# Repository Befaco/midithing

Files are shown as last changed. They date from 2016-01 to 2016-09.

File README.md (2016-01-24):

# MIDI Thing
Firmware for the [Befaco](http://befaco.org) Eurorack MIDI module (MIDI Thing).

## Requirements
You need Arduino >= 1.6.3.

Additionally you will need the following libraries installed (see the [Arduino Guide](https://www.arduino.cc/en/Guide/Libraries) on how to do this):

* [MIDI](https://github.com/FortySevenEffects/arduino_midi_library)
* [Bounce](https://github.com/thomasfredericks/Bounce2) (currently Bounce1 is needed. Please use it [until we've moved to Bounce2](https://github.com/Befaco/midithing/issues/3)).
* [mcp4728](https://code.google.com/p/neuroelec/downloads/detail?name=mcp4728_library-v1.3.zip)

## Uploading the firmware

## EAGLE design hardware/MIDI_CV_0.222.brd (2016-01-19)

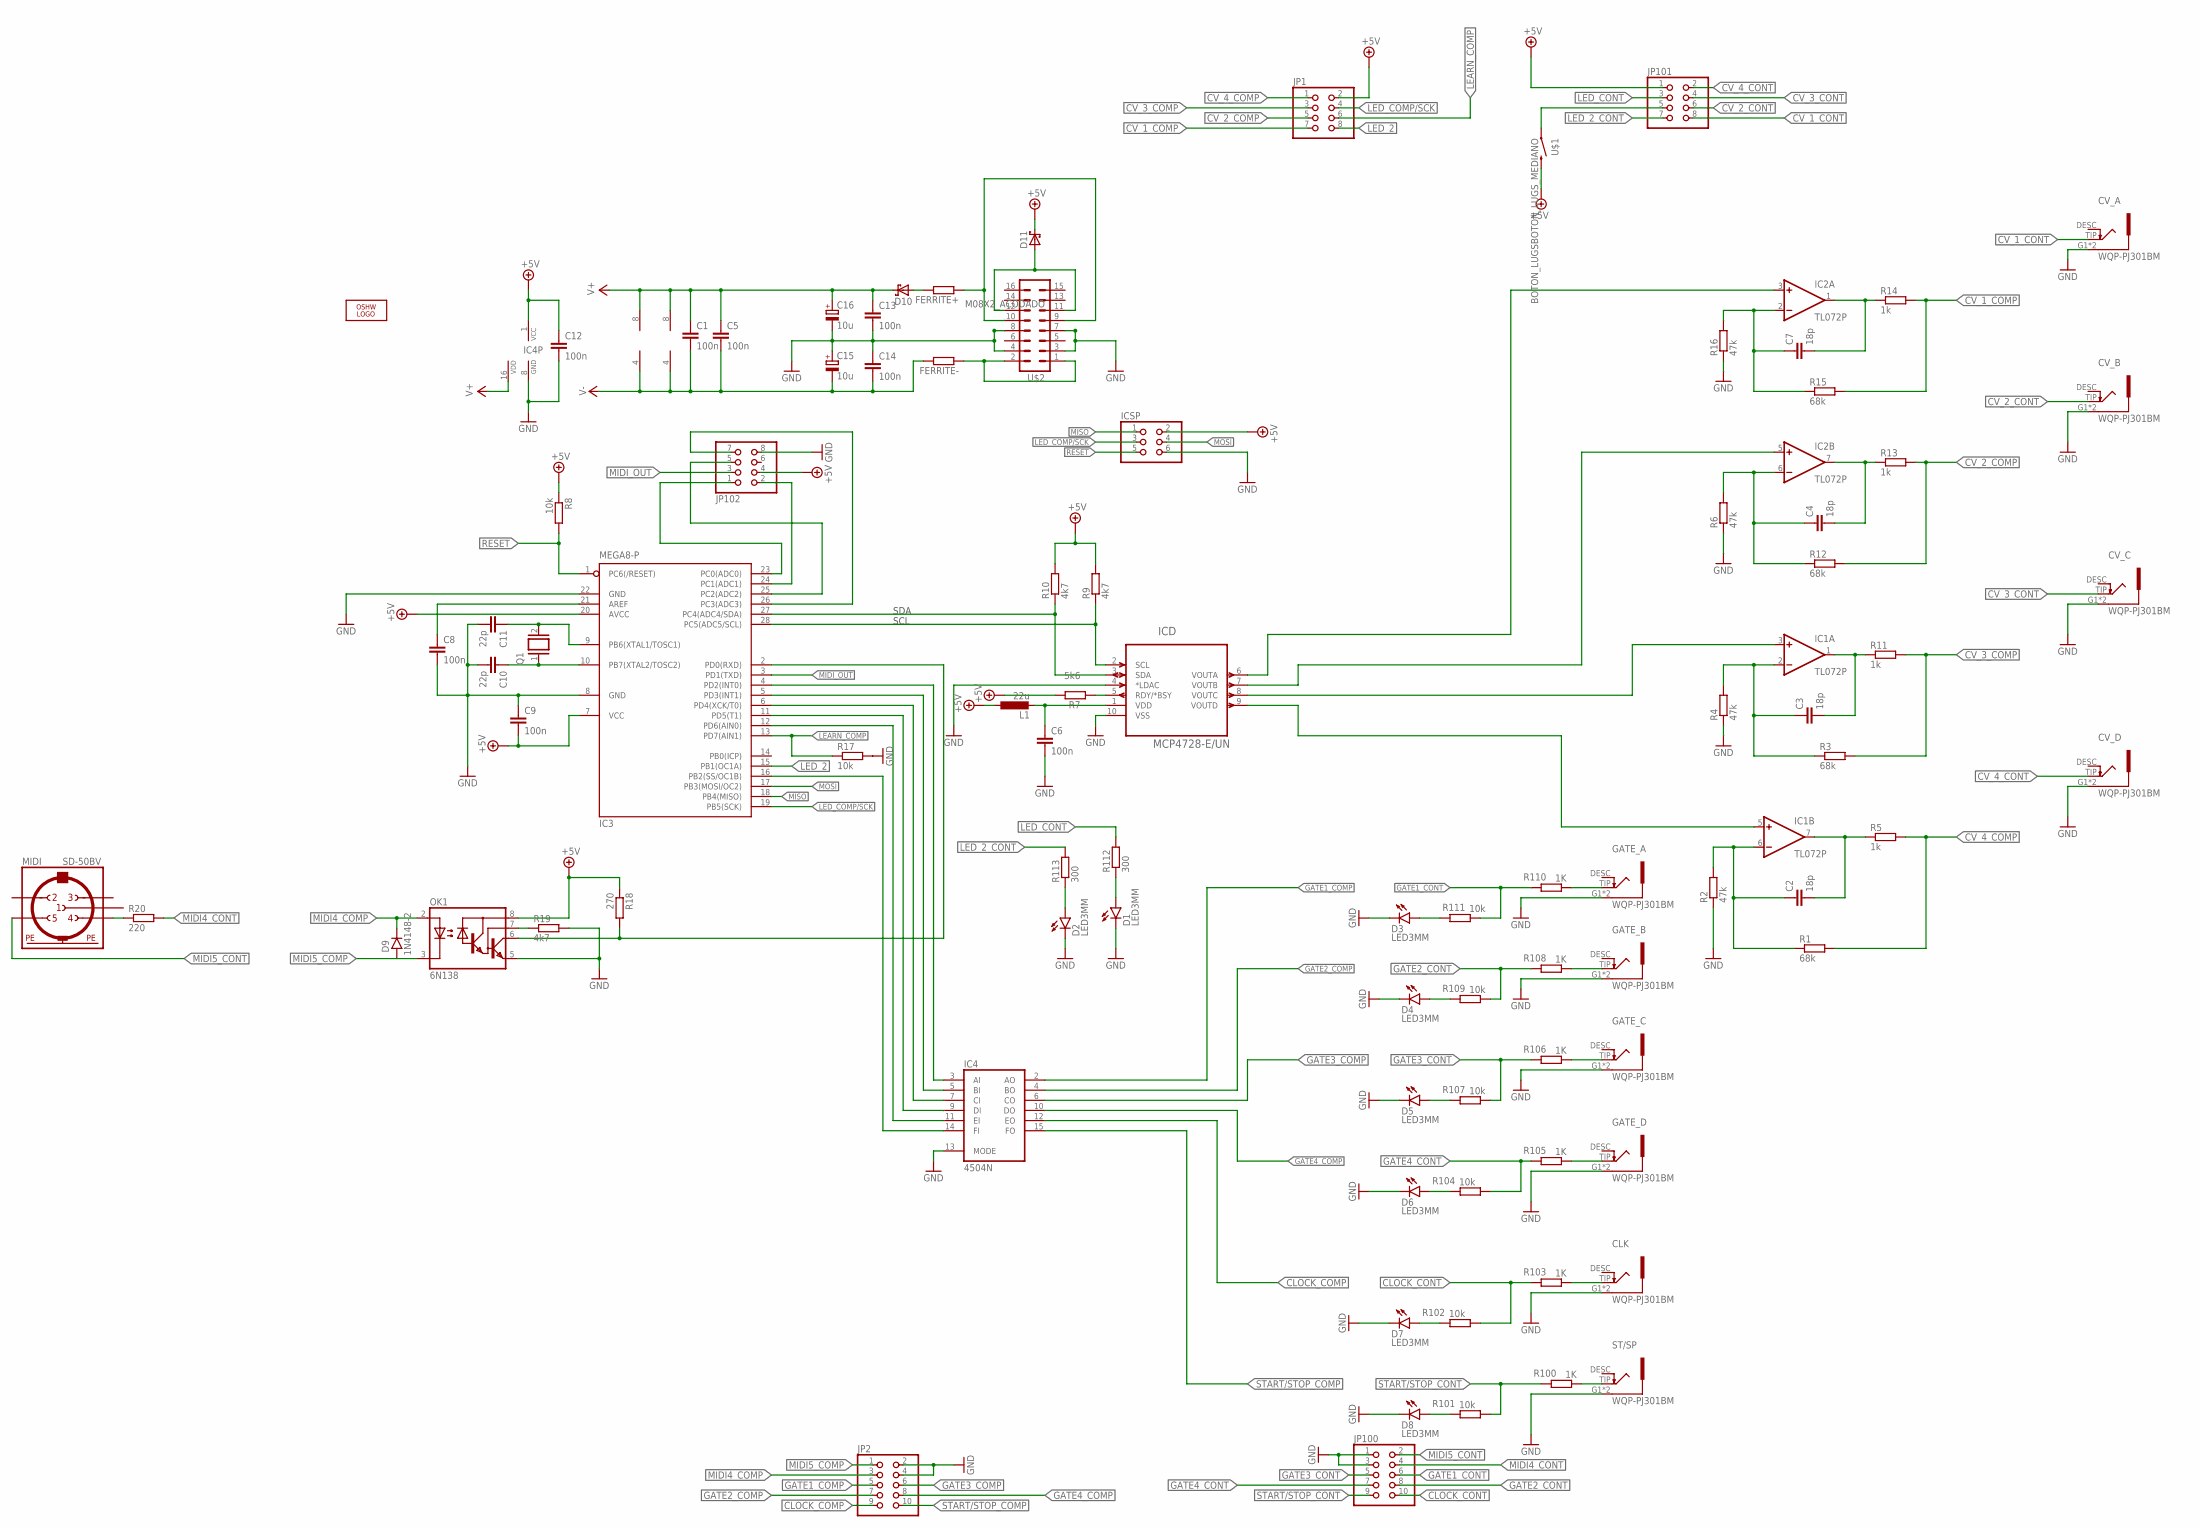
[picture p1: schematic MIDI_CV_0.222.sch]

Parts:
$1_35_$: OSHW_LOGO_FILLX0200-NT; OSHW_FILLX200_NOTEXT
C1, C5, C6, C8, C9, C12, C13, C14: 100n; C050-025X075
C2, C3, C4, C7: 18p; C050-025X075
C10, C11: 22p; C050-025X075
C15, C16: 10u; E2-4
CLK: WQP-PJ301BM
CV_A: WQP-PJ301BM
CV_B: WQP-PJ301BM
CV_C: WQP-PJ301BM
CV_D: WQP-PJ301BM
D1, D2, D3, D4, D5, D6, D7, D8: LED3MM
D9: 1N4148-2; DO35-2
D10, D11: SCHOTTKY-DIODEDO35-7; DO35-7
FERRITE+: R-EU_0204/5; 0204/5
FERRITE-: R-EU_0204/5; 0204/5
GATE_A: WQP-PJ301BM
GATE_B: WQP-PJ301BM
GATE_C: WQP-PJ301BM
GATE_D: WQP-PJ301BM
IC1, IC2: TL072P; DIL08
IC3: MEGA8-P; DIL28-3
IC4: 4504N; DIL16
ICD: MCP4728-E/UN; SOP50P490X110-10N
ICSP: PINHD-2X3; 2X03
JP1, JP101, JP102: PINHD-2X4; 2X04
JP2, JP100: PINHD-2X5; 2X05
L1: 22u; 0204/7
MIDI: SD-50BV
OK1: 6N138; DIL08
Q1: XTAL/S; QS
R1, R3, R12, R15: 68k; 0204/5
R2, R4, R6, R16: 47k; 0204/5
R5, R11, R13, R14: 1k; 0204/5
R7: 5k6; 0204/5
R8, R17, R101, R102, R104, R107, R109, R111: 10k; 0204/5
R9, R10, R19: 4k7; 0204/5
R18: 270; 0204/5
R20: 220; 0204/5
R100, R103, R105, R106, R108, R110: 1K; 0204/5
R112, R113: 300; 0204/5
ST/SP: WQP-PJ301BM
U$1: BOTON_LUGSBOTON_LUGS_MEDIANO; BOTON_LUGS_MEDIANO
U$2: M08X2_ACODADO; 2X8-POWER-ACODADO

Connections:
+5V: C9.2, C12.1, D11.C, IC3.7 (VCC), IC3.20 (AVCC), IC4.1 (VCC), ICSP.2, JP1.2, JP101.1, JP102.4, L1.1, OK1.8 (VCC), R7.2, R8.1, R9.2, R10.2, R18.1, U$1.P$2 (2)
A: IC2.3 (+IN), ICD.6 (VOUTA)
B: IC2.5 (+IN), ICD.7 (VOUTB)
C: IC1.3 (+IN), ICD.8 (VOUTC)
CLOCK_COMP: IC4.12 (EO), JP2.9
CLOCK_CONT: JP100.10, R102.1, R103.2
CV_1_COMP: JP1.7, R14.2, R15.2
CV_1_CONT: CV_A.TIP, JP101.8
CV_2_COMP: JP1.5, R12.2, R13.2
CV_2_CONT: CV_B.TIP, JP101.6
CV_3_COMP: JP1.3, R3.2, R11.2
CV_3_CONT: CV_C.TIP, JP101.4
CV_4_COMP: JP1.1, R1.2, R5.2
CV_4_CONT: CV_D.TIP, JP101.2
D: IC1.5 (+IN), ICD.9 (VOUTD)
DAC_A_FEEDBACK_T: C7.2, IC2.1 (OUT), R14.1
GATE1_COMP: IC4.2 (AO), JP2.5
GATE1_CONT: JP100.6, R110.2, R111.1
GATE2_COMP: IC4.4 (BO), JP2.7
GATE2_CONT: JP100.8, R108.2, R109.1
GATE3_COMP: IC4.6 (CO), JP2.6
GATE3_CONT: JP100.5, R106.2, R107.1
GATE4_COMP: IC4.10 (DO), JP2.8
GATE4_CONT: JP100.7, R104.1, R105.2
GND: C6.2, C8.2, C9.1, C10.2, C11.2, C12.2, C13.2, C14.1, C15.+, C16.-, CLK.G1 (SLEVE), CLK.G2 (SLEVE), CV_A.G1 (SLEVE), CV_A.G2 (SLEVE), CV_B.G1 (SLEVE), CV_B.G2 (SLEVE), CV_C.G1 (SLEVE), CV_C.G2 (SLEVE), CV_D.G1 (SLEVE), CV_D.G2 (SLEVE), D1.K (C), D2.K (C), D3.K (C), D4.K (C), D5.K (C), D6.K (C), D7.K (C), D8.K (C), GATE_A.G1 (SLEVE), GATE_A.G2 (SLEVE), GATE_B.G1 (SLEVE), GATE_B.G2 (SLEVE), GATE_C.G1 (SLEVE), GATE_C.G2 (SLEVE), GATE_D.G1 (SLEVE), GATE_D.G2 (SLEVE), IC3.8 (GND), IC3.22 (GND), IC4.8 (GND), IC4.13 (MODE), ICD.4 (*LDAC), ICD.10 (VSS), ICSP.6, JP2.2, JP2.4, JP100.1, JP100.3, JP102.8, OK1.5 (GND), R2.1, R4.1, R6.1, R16.1, R17.2, R19.2, ST/SP.G1 (SLEVE), ST/SP.G2 (SLEVE), U$2.3, U$2.4, U$2.7, U$2.8
LEARN_COMP: IC3.13 (PD7(AIN1)), JP1.6, R17.1
LED_2: IC3.15 (PB1(OC1A)), JP1.8
LED_2_CONT: JP101.7, R113.2
LED_COMP/SCK: IC3.19 (PB5(SCK)), ICSP.3, JP1.4
LED_CONT: JP101.3, R112.2
MIDI4_COMP: D9.C, JP2.3, OK1.2 (A)
MIDI4_CONT: JP100.4, R20.2
MIDI5_COMP: D9.A, JP2.1, OK1.3 (C)
MIDI5_CONT: JP100.2, MIDI.5
MIDI_OUT: IC3.3 (PD1(TXD)), JP102.3
MISO: IC3.18 (PB4(MISO)), ICSP.1
MOSI: IC3.17 (PB3(MOSI/OC2)), ICSP.4
unnamed: D7.A, R102.2
unnamed: C10.1, IC3.10 (PB7(XTAL2/TOSC2)), Q1.1
unnamed: FERRITE-.1, U$2.1, U$2.2
unnamed: IC3.23 (PC0(ADC0)), JP102.1
unnamed: C4.2, IC2.7 (OUT), R13.1
unnamed: C2.1, IC1.6 (-IN), R1.1, R2.2
unnamed: D1.A, R112.1
unnamed: JP101.5, U$1.P$1 (1)
unnamed: IC3.16 (PB2(SS/OC1B)), IC4.14 (FI)
unnamed: C3.2, IC1.1 (OUT), R11.1
unnamed: C7.1, IC2.2 (-IN), R15.1, R16.2
unnamed: IC3.24 (PC1(ADC1)), JP102.2
unnamed: R100.1, ST/SP.TIP
unnamed: IC3.25 (PC2(ADC2)), JP102.5
unnamed: C3.1, IC1.2 (-IN), R3.1, R4.2
unnamed: CLK.TIP, R103.1
unnamed: GATE_D.TIP, R105.1
unnamed: ICD.5 (RDY/*BSY), R7.1
unnamed: IC3.5 (PD3(INT1)), IC4.5 (BI)
unnamed: IC3.26 (PC3(ADC3)), JP102.7
unnamed: C2.2, IC1.7 (OUT), R5.1
unnamed: D11.A, U$2.11, U$2.12
unnamed: IC3.11 (PD5(T1)), IC4.9 (DI)
unnamed: D10.A, FERRITE+.2
unnamed: D2.A, R113.1
unnamed: GATE_A.TIP, R110.1
unnamed: C6.1, ICD.1 (VDD), L1.2
unnamed: C11.1, IC3.9 (PB6(XTAL1/TOSC1)), Q1.2
unnamed: IC3.12 (PD6(AIN0)), IC4.11 (EI)
unnamed: FERRITE+.1, U$2.9, U$2.10
unnamed: D3.A, R111.2
unnamed: D8.A, R101.2
unnamed: GATE_B.TIP, R108.1
unnamed: IC3.4 (PD2(INT0)), IC4.3 (AI)
unnamed: GATE_C.TIP, R106.1
unnamed: D4.A, R109.2
unnamed: IC3.6 (PD4(XCK/T0)), IC4.7 (CI)
unnamed: MIDI.4, R20.1
unnamed: C8.1, IC3.21 (AREF)
unnamed: D5.A, R107.2
unnamed: D6.A, R104.2
unnamed: OK1.7 (VB), R19.1
unnamed: IC3.2 (PD0(RXD)), OK1.6 (VO), R18.2
unnamed: C4.1, IC2.6 (-IN), R6.2, R12.1
RESET: IC3.1 (PC6(/RESET)), ICSP.5, R8.2
SCL_B: IC3.28 (PC5(ADC5/SCL)), ICD.2 (SCL), R9.1
SDA_T: IC3.27 (PC4(ADC4/SDA)), ICD.3 (SDA), R10.1
START/STOP_COMP: IC4.15 (FO), JP2.10
START/STOP_CONT: JP100.9, R100.2, R101.1
V+: C1.1, C5.1, C13.1, C16.+, D10.C, IC1.8 (V+), IC2.8 (V+), IC4.16 (VDD)
V-: C1.2, C5.2, C14.2, C15.-, FERRITE-.2, IC1.4 (V-), IC2.4 (V-)

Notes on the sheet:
SDA
SCL

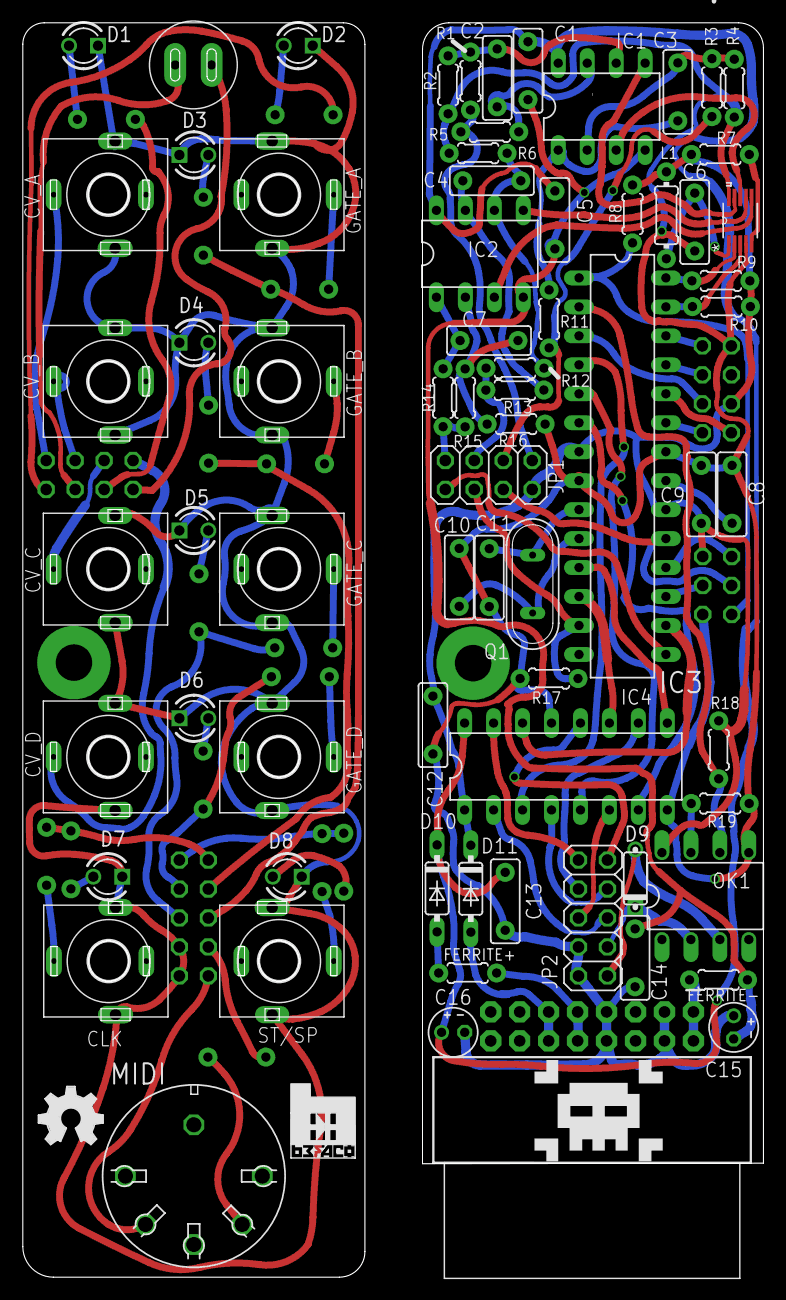
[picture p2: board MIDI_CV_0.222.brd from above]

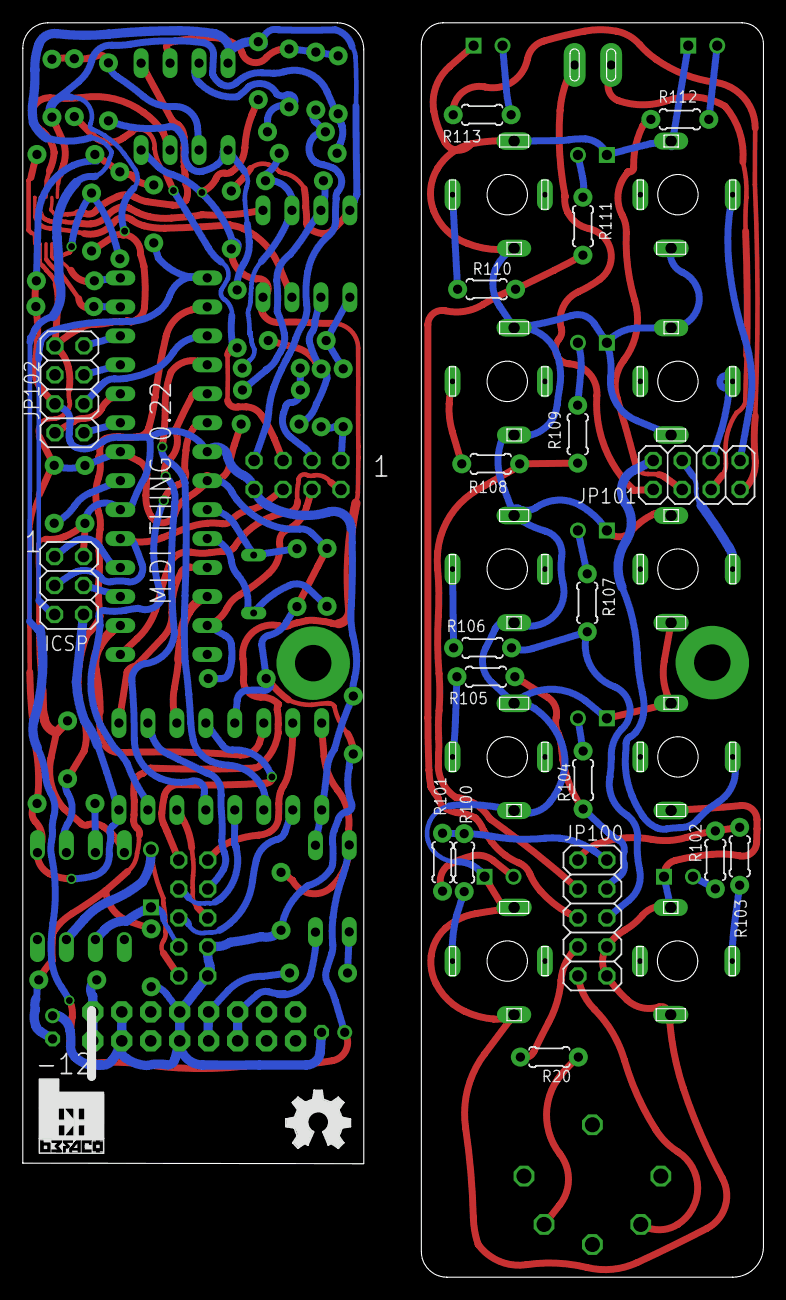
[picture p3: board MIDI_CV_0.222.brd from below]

Board: 2 copper layers, 64.9 x 110.0 mm, 95 parts (21 on the bottom side), 88 nets.

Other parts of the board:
LOGO1: OSHW_LOGO_FILLX0200-NT; OSHW_FILLX200_NOTEXT
U$3, U$100: LOGOBEFACOCONLETRAS; LOGOBEFACOCONLETRAS_2
U$4: CALAVERA

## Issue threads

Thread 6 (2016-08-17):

Learned lowest note is ignored

lijon, 2016-08-17:
When learning the lowest note, this note is then ignored. For example when learning the lowest C on a keyboard, it will then only recognize notes from C# and up.

Perhaps change https://github.com/Befaco/midithing/blob/master/firmware/MIDIClass.ino#L270 to do `minInput <= pitch` instead?

xustafu, 2016-08-31:
Checking this option.
The change suggested do work, so after learning first note is actually used.
Need some doublechecking as voltage for the first note is not consistent (~20mV)

lijon, 2016-09-01:
Perhaps it results in wrong index (-1 or so) at some other stage for table lookup, reading outside the array?

Closed 2018-12-11.

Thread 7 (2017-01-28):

Not possible to calibrate/tune lowest note

tangram, 2017-01-28:
Background: I have sequencers that cannot be tuned. To avoid having to constantly retune oscillators, I'd want one of these sequencers to be the reference, so that e.g. C4 on the sequencer equals C4 from the Midi Thing.

The Midi Thing is very tunable, no problem. But say I set the lowest note at B0, to be able to play from C1 and up (see issue #6). Calibration points are now at B0, F1, B1 and so on. But B0 is not tunable, as B0 and A#0 are out of range even when calibrating, resulting in a curve that goes very sharp or very flat from F1 and down to C1.

I realize that it wouldn't make sense to tune below 0V, but the lowest note is actually 0.333V on my multimeter. I realize also that this is a common problem with a modular setup, but allowing the lower note to be tuned on the Midi Thing can alleviate this somewhat.

Any input on this issue?

xustafu, 2017-03-21:
Hi there!

Sorry for the delayed reply! Check branch development for a solution for the lowest note not being learnt.
About minimum voltage, this is a know behaviour of the DAC, it never goes down to zero. But 0.3 v is actually quite high!

tangram, 2017-03-21:
Alright, thanks. I've been using the develop branch for the last month or so (from the last round of commits), although I haven't investigated this issue again. I'll do another update and see where it stands now.

Closed 2018-12-11.

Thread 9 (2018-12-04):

Atmega328p chip substitution method doesn't work

dsanz006, 2018-12-04:
so I bought an Arduino Uno and replaced its Atmega328p chip with the one in the Midi Thing, in order to update its firmware to V2. In the Arduino IDE the project compiles correctly, but when I try to upload it to the board I get the following errors:

`avrdude: stk500_recv(): programmer is not responding`
`avrdude: stk500_getsync() attempt 1 of 10: not in sync: resp=0x00`
`avrdude: stk500_getsync() attempt 2 of 10: not in sync: resp=0xf8`
`avrdude: stk500_getsync() attempt 3 of 10: not in sync: resp=0xc0`
`avrdude: stk500_getsync() attempt 4 of 10: not in sync: resp=0xf8`
`avrdude: stk500_getsync() attempt 5 of 10: not in sync: resp=0x80`
`avrdude: stk500_getsync() attempt 6 of 10: not in sync: resp=0xf8`
`avrdude: stk500_getsync() attempt 7 of 10: not in sync: resp=0x80`
`avrdude: stk500_getsync() attempt 8 of 10: not in sync: resp=0x00`
`avrdude: stk500_getsync() attempt 9 of 10: not in sync: resp=0xf8`
`avrdude: stk500_getsync() attempt 10 of 10: not in sync: resp=0xc0`
`Problem uploading to board.  See http://www.arduino.cc/en/Guide/Troubleshooting#upload for suggestions.`

However if I try it with the Atmega chip that came with the Arduino Uno board, everything is fine. So it seems to be something about the Atmega chip on the Midi Thing module.

I would really like to solve this, otherwise I am left with a useless Arduino Uno, with no Atmega328p chip.

xustafu, 2018-12-11:
This method will not work if Arduino bootloader was not loaded into MIDI thing.
This method slipped into v2 docu and should not be there. Sorry!!!

Please try using an external programmer, or a protoboard and Arduino as ISP sketch to load the program.

xustafu, 2019-03-22:
Setting as solved after  no feedback received.

Closed 2019-03-22.

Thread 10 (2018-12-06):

Updating Firmware

mightycoco, 2018-12-06:
I'm on Windows 10

I bought the same USBasp programmer, you mentioned in the README.md

I installed the drivers with zadig-2.4.exe using libusbK drivers. The device shows up in device manager without issues

I installed the latest Arduino IDE

I copied the MIDI, Bounde2, MCP4728 folders from your repo to the libraries folder of Arduino

Opened firmware.ino - compiling works without error. I also get a firmware.ino.hex

I configured the IDE:
Board: Arduino Nano
Processor: ATMega328P
Programmer: USBasp

Sketch -> Upload using programmer gives me errors:

	Sketch uses 17628 bytes (57%) of program storage space. Maximum is 30720 bytes.
	Global variables use 1387 bytes (67%) of dynamic memory, leaving 661 bytes for local variables. Maximum is 2048 bytes.
	C:\Program Files (x86)\Arduino\hardware\tools\avr/bin/avrdude -CC:\Program Files (x86)\Arduino\hardware\tools\avr/etc/avrdude.conf -v -patmega328p -cusbasp -Pusb -Uflash:w:C:\Users\xxx\AppData\Local\Temp\arduino_build_426070/firmware.ino.hex:i

	avrdude: Version 6.3-20171130
			 Copyright (c) 2000-2005 Brian Dean, http://www.bdmicro.com/
			 Copyright (c) 2007-2014 Joerg Wunsch

			 System wide configuration file is "C:\Program Files (x86)\Arduino\hardware\tools\avr/etc/avrdude.conf"

			 Using Port                    : usb
			 Using Programmer              : usbasp
			 AVR Part                      : ATmega328P
			 Chip Erase delay              : 9000 us
			 PAGEL                         : PD7
			 BS2                           : PC2
			 RESET disposition             : dedicated
			 RETRY pulse                   : SCK
			 serial program mode           : yes
			 parallel program mode         : yes
			 Timeout                       : 200
			 StabDelay                     : 100
			 CmdexeDelay                   : 25
			 SyncLoops                     : 32
			 ByteDelay                     : 0
			 PollIndex                     : 3
			 PollValue                     : 0x53
			 Memory Detail                 :

									  Block Poll               Page                       Polled
			   Memory Type Mode Delay Size  Indx Paged  Size   Size #Pages MinW  MaxW   ReadBack
			   ----------- ---- ----- ----- ---- ------ ------ ---- ------ ----- ----- ---------
			   eeprom        65    20     4    0 no       1024    4      0  3600  3600 0xff 0xff
			   flash         65     6   128    0 yes     32768  128    256  4500  4500 0xff 0xff
			   lfuse          0     0     0    0 no          1    0      0  4500  4500 0x00 0x00
			   hfuse          0     0     0    0 no          1    0      0  4500  4500 0x00 0x00
			   efuse          0     0     0    0 no          1    0      0  4500  4500 0x00 0x00
			   lock           0     0     0    0 no          1    0      0  4500  4500 0x00 0x00
			   calibration    0     0     0    0 no          1    0      0     0     0 0x00 0x00
			   signature      0     0     0    0 no          3    0      0     0     0 0x00 0x00

			 Programmer Type : usbasp
			 Description     : USBasp, http://www.fischl.de/usbasp/

	avrdude: auto set sck period (because given equals null)
	An error occurred while uploading the sketch
	avrdude: error: program enable: target doesn't answer. 1
	avrdude: initialization failed, rc=-1
			 Double check connections and try again, or use -F to override
			 this check.

	avrdude done.  Thank you.

Executing avrdude on the command line shows this:

avrdude -C"C:\Program Files (x86)\Arduino\hardware\tools\avr/etc/avrdude.conf" -v -p atmega328p -c usbasp

	avrdude: Version 6.3-20171130
			 Copyright (c) 2000-2005 Brian Dean, http://www.bdmicro.com/
			 Copyright (c) 2007-2014 Joerg Wunsch

			 System wide configuration file is "C:\Program Files (x86)\Arduino\hardware\tools\avr/etc/avrdude.conf"

			 Using Port                    : usb
			 Using Programmer              : usbasp
			 AVR Part                      : ATmega328P
			 Chip Erase delay              : 9000 us
			 PAGEL                         : PD7
			 BS2                           : PC2
			 RESET disposition             : dedicated
			 RETRY pulse                   : SCK
			 serial program mode           : yes
			 parallel program mode         : yes
			 Timeout                       : 200
			 StabDelay                     : 100
			 CmdexeDelay                   : 25
			 SyncLoops                     : 32
			 ByteDelay                     : 0
			 PollIndex                     : 3
			 PollValue                     : 0x53
			 Memory Detail                 :

									  Block Poll               Page                       Polled
			   Memory Type Mode Delay Size  Indx Paged  Size   Size #Pages MinW  MaxW   ReadBack
			   ----------- ---- ----- ----- ---- ------ ------ ---- ------ ----- ----- ---------
			   eeprom        65    20     4    0 no       1024    4      0  3600  3600 0xff 0xff
			   flash         65     6   128    0 yes     32768  128    256  4500  4500 0xff 0xff
			   lfuse          0     0     0    0 no          1    0      0  4500  4500 0x00 0x00
			   hfuse          0     0     0    0 no          1    0      0  4500  4500 0x00 0x00
			   efuse          0     0     0    0 no          1    0      0  4500  4500 0x00 0x00
			   lock           0     0     0    0 no          1    0      0  4500  4500 0x00 0x00
			   calibration    0     0     0    0 no          1    0      0     0     0 0x00 0x00
			   signature      0     0     0    0 no          3    0      0     0     0 0x00 0x00

			 Programmer Type : usbasp
			 Description     : USBasp, http://www.fischl.de/usbasp/

	avrdude: auto set sck period (because given equals null)
	avrdude: error: program enable: target doesn't answer. 1
	avrdude: initialization failed, rc=-1
			 Double check connections and try again, or use -F to override
			 this check.

	avrdude done.  Thank you.

What are the recommended settings to update the firmware with the same USBasp programmer you recommend in your README.md?

xustafu, 2018-12-11:
Seems you are compiling for Arduino Nano. Please try with UNO.

pinewavestudio, 2019-03-22:
I am having this same error message.  Did anyone figure this out?

xustafu, 2019-03-22:
Thansk a bunch for the feedback!!

Setting the issue as solved.

mightycoco, 2019-09-21:
Still having the same issue. Wasn't resolved for me by setting the right board.

"C:\Program Files (x86)\Arduino\hardware\tools\avr/bin/avrdude" -CC:"\Program Files (x86)\Arduino\hardware\tools\avr/etc/avrdude.conf" -v -patmega328p -cusbasp -Pusb -Uflash:w:C:\Users\xxx\AppData\Local\Temp\builda3f5bb2dc51d34f6c4eeaa8f0274de71.tmp/firmware.ino.hex:i

avrdude: Version 6.3, compiled on Feb 17 2016 at 09:25:53
         Copyright (c) 2000-2005 Brian Dean, http://www.bdmicro.com/
         Copyright (c) 2007-2014 Joerg Wunsch

         System wide configuration file is "C:\Program Files (x86)\Arduino\hardware\tools\avr/etc/avrdude.conf"
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
mightycoco, 2019-09-22:
Does the board has to be powered by the eurorack power supply? Couldn't find any information on this. The documentation for upgrading the firmware is lacking a lot of information and it's really quite of a hassle...

mightycoco, 2019-12-05:
Any news on this?

jeremybernstein, 2019-12-06:
Did you try powering the board? I'm not in my studio to check, but I think you do need a powered module in order to update the chip.

mightycoco, 2019-12-06:
That was actually the question, because I'm unsure about that and it isn't documented. I didn't want to try powering the module in my rack along connecting the programmer before I blow things up.

I'm a noob in flashing firmwares to modules and there are different conflicting documentations to be found online. I'm really missing a detailed step-by-step guide for the average musician...

jeremybernstein, 2019-12-06:
I hear you. You won't blow anything up, I promise. Give that a try, please.

starmandeluxe, 2020-08-28:
I am having the same issue actually, and I do have the module powered on, the pin orientation is correct, and also using USBasp with the fixed libusbK driver to program. I am getting this output:

`Arduino: 1.8.8 (Windows 10), TD: 1.45, Board: "Arduino Uno"

Sketch uses 18224 bytes (56%) of program storage space. Maximum is 32256 bytes.
Global variables use 1397 bytes (68%) of dynamic memory, leaving 651 bytes for local variables. Maximum is 2048 bytes.
C:\Users\AppData\Local\Arduino15\packages\arduino\tools\avrdude\6.3.0-arduino17/bin/avrdude -CC:\Users\AppData\Local\Arduino15\packages\arduino\tools\avrdude\6.3.0-arduino17/etc/avrdude.conf -v -patmega328p -cusbasp -Pusb -Uflash:w:C:\Users\AppData\Local\Temp\arduino_build_193372/firmware.ino.hex:i

avrdude: Version 6.3, compiled on Feb 17 2016 at 09:25:53
         Copyright (c) 2000-2005 Brian Dean, http://www.bdmicro.com/
         Copyright (c) 2007-2014 Joerg Wunsch

         System wide configuration file is "C:\Users\AppData\Local\Arduino15\packages\arduino\tools\avrdude\6.3.0-arduino17/etc/avrdude.conf"

         Using Port                    : usb
         Using Programmer              : usbasp
         AVR Part                      : ATmega328P
         Chip Erase delay              : 9000 us
         PAGEL                         : PD7
         BS2                           : PC2
         RESET disposition             : dedicated
         RETRY pulse                   : SCK
         serial program mode           : yes
         parallel program mode         : yes
         Timeout                       : 200
         StabDelay                     : 100
         CmdexeDelay                   : 25
         SyncLoops                     : 32
         ByteDelay                     : 0
         PollIndex                     : 3
         PollValue                     : 0x53
         Memory Detail                 :

                                  Block Poll               Page                       Polled
           Memory Type Mode Delay Size  Indx Paged  Size   Size #Pages MinW  MaxW   ReadBack
           ----------- ---- ----- ----- ---- ------ ------ ---- ------ ----- ----- ---------
           eeprom        65    20     4    0 no       1024    4      0  3600  3600 0xff 0xff
           flash         65     6   128    0 yes     32768  128    256  4500  4500 0xff 0xff
           lfuse          0     0     0    0 no          1    0      0  4500  4500 0x00 0x00
           hfuse          0     0     0    0 no          1    0      0  4500  4500 0x00 0x00
           efuse          0     0     0    0 no          1    0      0  4500  4500 0x00 0x00
           lock           0     0     0    0 no          1    0      0  4500  4500 0x00 0x00
           calibration    0     0     0    0 no          1    0      0     0     0 0x00 0x00
           signature      0     0     0    0 no          3    0      0     0     0 0x00 0x00

         Programmer Type : usbasp
         Description     : USBasp, http://www.fischl.de/usbasp/

avrdude: auto set sck period (because given equals null)
avrdude: warning: cannot set sck period. please check for usbasp firmware update.
avrdude: error: program enable: target doesn't answer. 1
avrdude: initialization failed, rc=-1
         Double check connections and try again, or use -F to override
         this check.

avrdude done.  Thank you.

the selected serial port
 does not exist or your board is not connected
`

Any ideas?

Closed 2019-03-22.

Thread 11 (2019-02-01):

Error compiling firmware v.2

mihozu, 2019-02-01:
Hello,

I'm trying to upgrade my midi thing with firmware v.2.
I'm however encountering an issue when compiling the code, seems an error with the mcp4728 library :

firmware:50:1: error: 'mcp4728' does not name a type
 mcp4728 Dac = mcp4728(0); // instantiate mcp4728 object, Device ID = 0
 ^
/Users/mihozu/Documents/Arduino/firmware/firmware.ino: In function 'void setup()':
firmware:108:3: error: 'Dac' was not declared in this scope
   Dac.begin();  // initialize i2c interface
   ^
/Users/mihozu/Documents/Arduino/firmware/firmware.ino: In function 'void SendvaltoDAC(unsigned int, unsigned int)':
firmware:268:3: error: 'Dac' was not declared in this scope
   Dac.analogWrite(port, val); // write to input register of a DAC. Channel 0-3, Value 0-4095
   ^
exit status 1
'mcp4728' does not name a type

I wonder if I have the right mcp4728 library version,
the arduino library manager shows version 0.1.0

xustafu, 2020-01-24:
That might be the case. did you tried downloading the library and adding it manually?

max-circlefade, 2020-03-06:
Same here

thomasemilhansen, 2021-11-08:
You also have to change line 65 in firmware.ino to "struct MIDISettings : public midi::DefaultSerialSettings" if you're using the latest version of the MIDI library (as per November 2021).

xustafu, 2021-11-09:
Updated instructions to reflect more clearly MCP library link.
Updated code to be compatible with MIDI v5.0.2
check commit:

Closed 2021-11-09.

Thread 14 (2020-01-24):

Retrigger works only partially

klangmodulator, 2020-01-24:
Tried to use the retrigger feature of the midithing v2.1. Unfortunately the retrigger ON doesn't work in MONO mode, in DUAL mode only on the first voice and in QUAD mode only on first 3 voices.

I think I spotted the reason: in the function `MIDICV::playNote()` the gate pin is used as an index for the `Retrig` array, ranging between 2 to 5. In the `ProcessTrigger()` function in firmware.ino this array is parsed from 1 to `GS.NumVoices`.

xustafu, 2020-01-24:
Seems like a bug indeed. Checking it, will come back to you the soonest!

xustafu, 2021-11-09:
Completely forgot to adress this issue!!! There was a firmware change but not uploaded, sorry!
Can you please check if Test branch solves your issue?
https://github.com/Befaco/midithing/tree/Test

klangmodulator, 2021-11-17:
Thanks for coming back on it. I tested it in MONO/DUAL/QUAD mode and yes, the retrigger works now as it should! cool

The only thing I had to change was to rename the include file `#include <mcp4728.h>` to `#include <MCP4728.h>` so that the sketch compiled on my machine (built with Arduino 1.8.16 on Win10 and I installed the MCP4728 arduino library version 0.1.0 by "hideakitai")

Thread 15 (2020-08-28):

Avrdude failing to connect to USBasp programmer

starmandeluxe, 2020-08-28:
I am having a very similar issue as in https://github.com/Befaco/midithing/issues/10

I do have the module powered on, the pin orientation is correct, and also using USBasp with the fixed libusbK driver to program. I am getting this output:

```Arduino: 1.8.8 (Windows 10), TD: 1.45, Board: "Arduino Uno"

Sketch uses 18224 bytes (56%) of program storage space. Maximum is 32256 bytes.
Global variables use 1397 bytes (68%) of dynamic memory, leaving 651 bytes for local variables. Maximum is 2048 bytes.
C:\Users\AppData\Local\Arduino15\packages\arduino\tools\avrdude\6.3.0-arduino17/bin/avrdude -CC:\Users\AppData\Local\Arduino15\packages\arduino\tools\avrdude\6.3.0-arduino17/etc/avrdude.conf -v -patmega328p -cusbasp -Pusb -Uflash:w:C:\Users\AppData\Local\Temp\arduino_build_193372/firmware.ino.hex:i

avrdude: Version 6.3, compiled on Feb 17 2016 at 09:25:53
Copyright (c) 2000-2005 Brian Dean, http://www.bdmicro.com/
Copyright (c) 2007-2014 Joerg Wunsch

     System wide configuration file is "C:\Users\AppData\Local\Arduino15\packages\arduino\tools\avrdude\6.3.0-arduino17/etc/avrdude.conf"

     Using Port                    : usb
     Using Programmer              : usbasp
     AVR Part                      : ATmega328P
     Chip Erase delay              : 9000 us
     PAGEL                         : PD7
     BS2                           : PC2
     RESET disposition             : dedicated
     RETRY pulse                   : SCK
     serial program mode           : yes
     parallel program mode         : yes
     Timeout                       : 200
     StabDelay                     : 100
     CmdexeDelay                   : 25
     SyncLoops                     : 32
     ByteDelay                     : 0
     PollIndex                     : 3
     PollValue                     : 0x53
     Memory Detail                 :

                              Block Poll               Page                       Polled
       Memory Type Mode Delay Size  Indx Paged  Size   Size #Pages MinW  MaxW   ReadBack
       ----------- ---- ----- ----- ---- ------ ------ ---- ------ ----- ----- ---------
       eeprom        65    20     4    0 no       1024    4      0  3600  3600 0xff 0xff
       flash         65     6   128    0 yes     32768  128    256  4500  4500 0xff 0xff
       lfuse          0     0     0    0 no          1    0      0  4500  4500 0x00 0x00
       hfuse          0     0     0    0 no          1    0      0  4500  4500 0x00 0x00
       efuse          0     0     0    0 no          1    0      0  4500  4500 0x00 0x00
       lock           0     0     0    0 no          1    0      0  4500  4500 0x00 0x00
       calibration    0     0     0    0 no          1    0      0     0     0 0x00 0x00
       signature      0     0     0    0 no          3    0      0     0     0 0x00 0x00

     Programmer Type : usbasp
     Description     : USBasp, http://www.fischl.de/usbasp/
avrdude: auto set sck period (because given equals null)
avrdude: warning: cannot set sck period. please check for usbasp firmware update.
avrdude: error: program enable: target doesn't answer. 1
avrdude: initialization failed, rc=-1
Double check connections and try again, or use -F to override
this check.

avrdude done. Thank you.

the selected serial port
does not exist or your board is not connected
```

Any ideas?

xustafu, 2020-08-28:
Make sure USBasp pinout matches MIDI thing ICSP pinout:

https://befaco.org/docs/MIDI_Thing/Midi_Thing%20_V1_Schematic.pdf

xustafu, 2020-08-28:
Oh! Just read you doublechecked already the pinout sorry!!
Can you send me pics of the programmer you got?

starmandeluxe, 2020-08-30:
@xustafu, sure. Here is the front and back:

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

xustafu, 2020-08-31:
Programemr looks like the one we use here. What about voltage jumper. Is it set to 5v?
On Arduino, are you using the option sketch > Upload using programmer?
In module side. Can you check that pins from the connector has continuity to the relevant pin in the uController?

starmandeluxe, 2020-08-31:
@xustafu Thanks for checking.

Jumper is set to 5v. I'm using "upload using programmer". I have confirmed continuity with all 6 pins from programmer to module side.

Not sure what else could be the issue... By the way I have v1 of the module. Maybe I need an older firmware and not the latest commit? Or maybe I can just purchase the preloaded firmware IC and I can use it? Actually my module seems to be bugged out and won't respond to button press or midi, startup sequence doesn't run either. It starts up with LEDs 1, 2, and 4 lit and then goes dark. So that's why I am trying to reprogram it.

xustafu, 2020-09-01:
There is a chance the MCU is fried. Try burning the bootloader first... maybe its that? If not, you can get a new one in Akihabara and flash it.
If that fails, you can always get a new one pre-programmer from us... but would not like to spoil the fun from you :D

starmandeluxe, 2020-09-02:
Thanks a bunch @xustafu. I'm gonna close this for now, I'll try resetting bootloader and if that doesn't work I'll see if I can replace the part :)

starmandeluxe, 2021-07-22:
Just to follow-up, I bought a new Atmega328, replaced it in the module, flashed the bootloader, and then loaded the latest firmware, and now the module is back in business again!!!! It was exactly like you said :)
So if anyone else sees the error "the selected serial port does not exist or your board is not connected" and if you tried everything else, the hardware may be the issue. Thank you!

Closed 2020-09-02.

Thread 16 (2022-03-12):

Round-robin voice assignement in duo and poly modes

thomasemilhansen, 2022-03-12:
Hi all, I implemented round-robin voice assignment in duo and poly modes. Currently voices are assigned from low to high (_lowest_ free voice is assigned on key down). In round-robin mode they are cycled (_next_ free voice is assigned on key down). This opens up for some interesting patches a la MonoPoly and Vermona Perfourmer. I made it so that it's possible to switch between the two modes, using midi channel 3 notes C and D respectively in the configuration menu. I'm new to open source software and unsure how to propose this feature using pull requests. If you want this feature added to the firmware please advise and I will happily share it with everybody.

xustafu, 2022-03-15:
Great stuff! Created branch #RoundRobin so you can do a PR so we all can take a look. Thanks a bunch! in advance :)

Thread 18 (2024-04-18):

MIDI Thing v2

lateshift, 2024-04-18:
Heya!

Are the MIDI Thing v2 sources "hiding" in here?

Thanks 👏 ✌️
Jens

xustafu, 2024-04-18:
Nope!
This is MIDI Thing 1 code :)
MIDI Thing 2 will come after module is released!

Closed 2024-04-18.

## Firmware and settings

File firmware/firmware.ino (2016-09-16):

// Copyright 2014 Sergio Retamero.
//
// Author: Sergio Retamero (sergio.retamero@gmail.com)
//
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
// See http://creativecommons.org/licenses/MIT/ for more information.
//
// -----------------------------------------------------------------------------
//

#include "firmware.h"
#include "Blinker.h"
#include "MIDIClass.h"
#include "MultiPointConv.h"

//////////////////////////////////////////////
//Variables

// Var I2C DAC
mcp4728 Dac = mcp4728(0); // instantiate mcp4728 object, Device ID = 0
MultiPointConv DACConv[4];

// Var Learn Mode
byte LearnMode = NORMALMODE;
unsigned long LearnInitTime;
byte LearnStep = 0;

// Var Blinker
Blinker Blink((byte)PINLED);
Blinker Gates[10];

Bounce Bouncer = Bounce(); // will be configured in setup()
unsigned long BouncerLastTime = 0;

struct MIDISettings : public midi::DefaultSettings {
  static const bool UseRunningStatus = false;
  static const bool Use1ByteParsing = false;
};

MIDI_CREATE_CUSTOM_INSTANCE(HardwareSerial, Serial, MIDI, MIDISettings);

//////////////////////////////////////////////
// Initialization
void setup()
{
  // Configure digital outputs
  pinMode(PINLED, OUTPUT);
  digitalWrite(PINLED, LOW); // Set internal pull down resistor
  pinMode(PINLED2, OUTPUT);
  digitalWrite(PINLED2, LOW); // Set internal pull down resistor
  pinMode(PINGATE, OUTPUT);
  digitalWrite(PINGATE, LOW); // Set internal pull down resistor
  pinMode(PINGATE2, OUTPUT);
  digitalWrite(PINGATE2, LOW); // Set internal pull down resistor
  pinMode(PINGATE3, OUTPUT);
  digitalWrite(PINGATE3, LOW); // Set internal pull down resistor
  pinMode(PINGATE4, OUTPUT);
  digitalWrite(PINGATE4, LOW); // Set internal pull down resistor
  pinMode(PINSTARTSTOP, OUTPUT);
  digitalWrite(PINSTARTSTOP, LOW); // Set internal pull down resistor
  pinMode(PINCLOCK, OUTPUT);
  digitalWrite(PINCLOCK, LOW); // Set internal pull down resistor

  pinMode(PINLEARN, INPUT); // maybe INPUT_PULLUP?
  // Attach the Bounce object with a 50 millisecond debounce time
  Bouncer.attach(PINLEARN);
  Bouncer.interval(50);
  //digitalWrite(PINLEARN, LOW); // Set internal pull down resistor

  // DAC MCP4728 init
  Dac.begin();  // initialize i2c interface
  Dac.vdd(5000); // set VDD(mV) of MCP4728 for correct conversion between LSB and Vout
  Dac.setVref(1, 1, 1, 1); // Use internal vref
  Dac.setGain(1, 1, 1, 1); // Use gain x2
  for (int i = 0; i < 4; i++) {
    DACConv[i].DACnum = i;
  }

  // Init triggers gates
  Gates[0].pinLED = PITCHCV + 128;
  Gates[1].pinLED = VELOC + 128;
  Gates[2].pinLED = MODUL + 128;
  Gates[3].pinLED = BEND + 128;
  Gates[4].pinLED = PINCLOCK;
  Gates[5].pinLED = PINGATE;
  Gates[6].pinLED = PINGATE2;
  Gates[7].pinLED = PINGATE3;
  Gates[8].pinLED = PINGATE4;
  Gates[9].pinLED = PINSTARTSTOP;

  //  Init MIDI:
  //Serial.begin(115200);
  MIDI.turnThruOff(); // Thru off disconnected
  MIDI.setHandleNoteOn(HandleNoteOn); // Handle for NoteOn
  MIDI.setHandleNoteOff(HandleNoteOff); // Handle for NoteOff
  MIDI.setHandlePitchBend(HandlePitchBend); // Handle for Pitch Bend
  MIDI.setHandleControlChange(HandleControlChange); // Handle for CC
#ifdef STARTSTOPCONT
  MIDI.setHandleStart(HandleStart); // Handle Start, Continue, Stop
  MIDI.setHandleContinue(HandleContinue);
  MIDI.setHandleStop(HandleStop);
#endif
  MIDI.setHandleClock(HandleClock);
  MIDI.begin(MIDI_CHANNEL_OMNI); // Listen to all channels

#ifdef PRINTDEBUG
  Serial.println("Init MIDItoCV...");
#endif

  // Read MIDI Channels from EEPROM and store
  if (ReadMIDIeeprom() == -1) {
#ifdef PRINTDEBUG
    Serial.println("No EEPROM Read");
#endif
    // Set Mode manually
    //SetVoiceMode(MONOMIDI);
    //SetVoiceMode(DUALMIDI);
    SetVoiceMode(POLYFIRST);
    //SetVoiceMode(PERCTRIG);
  }

  // LDAC pin must be grounded for normal operation.
  // Reset DAC values to 0 after reset
  delay(50);
  Dac.analogWrite(0, 0, 0, 0);

#ifdef CALIBRATION
  analogReference(INTERNAL);
#endif
}

//////////////////////////////////////////////
// Main Loop
void loop()
{
  // put your main code here, to run repeatedly:

  MIDI.read();

  // handle blinks
  Blink.playBlink();
  for (int i = 0; i < 10; i++) {
    Gates[i].playBlink();
  }

  // Cal/Learn Button
  if (Bouncer.update()) { // button state changed
    unsigned long now = millis();
    unsigned long bouncerDuration = now - BouncerLastTime;

    BouncerLastTime = now;

    // Check for learn/cal mode signal
    if (Bouncer.fell()) {
      // If button pressed during calbration, end calibration
      if (LearnMode == ENTERCAL) {
        EndCalMode();
      }
      // Enter Calmode after 5 secs button press
      else if (bouncerDuration > 5000) {
        EnterCalMode();
      }
      // More than one second: Learn Mode
      else if (bouncerDuration > 1000) {
        EnterLearnMode();
      }
      // Panic
      else if (bouncerDuration > 100) {
        AllNotesOff();
      }
    }
  } else { // no change to the button state
    // In Learn mode, enter learn cycle
    if (LearnMode == ENTERLEARN) {
      DoLearnCycle();
    } else if (LearnMode == ENTERCAL) {
      DoCalCycle();
    }
  }
}

//////////////////////////////////////////////
// DAC function definition
// Send value val to DAC port
void  SendvaltoDAC(unsigned int port, unsigned int val)
{
  Dac.analogWrite(port, val); // write to input register of a DAC. Channel 0-3, Value 0-4095

#ifdef PRINTDEBUG
  Serial.print(port);
  Serial.print(" DAC = ");
  Serial.println(val);
#endif
}

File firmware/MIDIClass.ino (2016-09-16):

// Copyright 2014 Sergio Retamero.
//
// Author: Sergio Retamero (sergio.retamero@gmail.com)
//
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
// See http://creativecommons.org/licenses/MIT/ for more information.
//
// -----------------------------------------------------------------------------
//

MIDICV Voice[4];
int NumVoices = 0; // Number of MIDI channels in use
int VoiceMode = QUADMIDI; // MIDI mode Set to quad mode by default

// Actions to perform for Note On
void MIDICV::processNoteOn(byte pitch, byte velocity)
{
#ifdef PRINTDEBUG
  Serial.print(pitch);
  Serial.print(" noteon / v ");
  Serial.println(velocity);
  printNotes();
#endif

  if (notes.getCount() >= MAXNOTES) return; // as fast as possible

  // Add a new note to the note on list
  // First check if already in the list (should not happen, but...)
  // If not repeated, increase pressed key counter and store it
  if (!checkRepeat(pitch)) {
    notes.setPlaying(pitch, velocity);
    playNote(pitch, velocity);
  }
#ifdef PRINTDEBUG
  else {
    Serial.print("repeat");
  }

  Serial.print(" rep / Notes On: ");
  Serial.println(notes.getCount());
  printNotes();
#endif
}

// Actions to perform for Note Off
void MIDICV::processNoteOff(byte pitch)
{
#ifdef PRINTDEBUG
  Serial.print(pitch);
  Serial.print(" noteoff / v ");
  printNotes();
#endif

  if (!notes.getCount()) return; // as fast as possible

  // First check if the note off is in the list
  int repeat;
  repeat = checkRepeat(pitch);
  if (!repeat) {
#ifdef PRINTDEBUG
    Serial.println("Note on for received note off not found");
#endif
    return; // Note on for received note off not found
  }
  if (!notes.setPlaying(pitch, 0)) {
    playNoteOff(); //Leaving Pitch and velocity value and Gate down
#ifdef PRINTDEBUG
    Serial.print(" Last Note Off: ");
    Serial.println(pitch);
#endif
  }
  else {
    byte lastPitch, lastVelocity;
    if (notes.getLastEvent(&lastPitch, &lastVelocity)) {
      playNote(lastPitch, lastVelocity);
    }
#ifdef PRINTDEBUG
    Serial.print(repeat);
    Serial.print(" rep / Notes On: ");
    Serial.println(notes.getCount());
    printNotes();
#endif
  }
}

// Actions to perform for Pitch Bend
void MIDICV::processBend(int bend)
{
  unsigned int voltage = 0;

  if (bendDAC == NULL) {
    return;
  }

  voltage = bendDAC->linealConvert(bend);
  if (voltage > 4095) {
    voltage = 0;
  }

#ifdef PRINTDEBUG
  Serial.print("pitch bend: ");
  Serial.print(bend);
  Serial.print(" volt: ");
  Serial.println(voltage);
#endif
  SendvaltoDAC(bendDAC->DACnum, voltage);
}

// Actions to perform for Modulation change
void MIDICV::processMod(byte value)
{
  unsigned int voltage = 0;
  if (modDAC == NULL) {
    return;
  }
  // Convert to voltage
  voltage = modDAC->linealConvert(value);
  if (voltage > 4095) {
    voltage = 0;
  }

#ifdef PRINTDEBUG
  Serial.print("Modulation: ");
  Serial.print(value);
  Serial.print(" volt: ");
  Serial.println(voltage);
#endif
  SendvaltoDAC(modDAC->DACnum, voltage);
}

#ifdef PRINTDEBUG
void MIDICV::printNotes(void)
{
  for (int i = 0; i < notes.getCount(); i++) {
    byte pitch, velocity;
    notes.getEvent(i, &pitch, &velocity);
    Serial.print(pitch);
    Serial.print("/");
    Serial.print(velocity);
    Serial.print(" ");
  }
  Serial.println(" ");
}
#endif

// Check if the note is in the list and return position
byte MIDICV::checkRepeat(byte pitch)
{
  if (notes.getCount() < 1) {
    return (0);
  }

  if (notes.isPlaying(pitch)) {
    return (1);
  }
  return (0);
}

// Play Notes to DAC and pin outputs
void MIDICV::playNote(byte note, byte plvelocity)
{
  unsigned int voltage = 0;
  unsigned int voltage2 = 0;

  if (pitchDAC != NULL) {
    voltage = pitchDAC->intervalConvert(note);
    if (voltage > 4095) {
      voltage = 4095;
    }
    SendvaltoDAC(pitchDAC->DACnum, voltage);
  }

  if (velDAC != NULL) {
    voltage2 = velDAC->linealConvert(plvelocity);
    if (voltage2 > 4095) {
      voltage2 = 4095;
    }
    SendvaltoDAC(velDAC->DACnum, voltage2);
  }

  if (plvelocity == 0) { //NOTE OFF
    playNoteOff();
  } else if (gatePin != -1) {
    digitalWrite(gatePin, HIGH);
  }
}

// All Notes off
void MIDICV::playNoteOff(void)
{
  if (gatePin != -1) {
    digitalWrite(gatePin, LOW);
  }
}

// Note on received in Learn Mode
// Capture channel and new minimum note
void MIDICV::LearnThis(byte channel, byte pitch, byte velocity)
{
  if (pitchDAC == NULL) {
    return;
  }
  // Learn channel and clock
  midiChannel = channel;
  // Set new minimum pitch
  pitchDAC->minInput = pitch;
#ifdef PRINTDEBUG
  Serial.print(channel);
  Serial.print(" Channel. New min Input: ");
  Serial.println(pitch);
  Serial.print(LearnStep);
  Serial.println(" Step, End Learn Mode");
#endif
  LearnInitTime = millis();
  notes.clear();

  // Go to next channel learn step.
  if (LearnStep < NumVoices - 1 && LearnStep < 3) {
    LearnStep++;
  } else {
    // Set normal mode
    LearnMode = NORMALMODE;
    LearnStep = 0;
    // Turn off LED
    Blink.setBlink(0, 0, 0);
    // Store value in EEPROM
    WriteMIDIeeprom();
  }
}

///////////////////////////////////
// Support functions for MIDI class

// Check percussion notes and return associated gate
int PercussionNoteGate(byte pitch)
{
  switch (pitch) {
  case 36:
    return (0);
  case 38:
    return (1);
  case 42:
    return (2);
  case 45:
    return (3);
  case 47:
    return (5);
  case 48:
    return (6);
  case 49:
    return (7);
  case 51:
    return (8);
  }
  return (-1);
}

// Check if received channel is any active MIDI
void AllNotesOff(void)
{
  for (int i = 0; i < NumVoices; i++) {
    Voice[i].playNoteOff();
    Voice[i].notes.clear();
  }
}
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

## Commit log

2016-01-18 remove firmware debug folder, which contains duplicates. Using #ifdefs to switch debugging on and off is fine and simplifies the repository.
2016-01-19 Added Release Candidate hardware design
    [MIDI_CV_0.222.brd, MIDI_CV_0.222.sch]
2016-01-24 Made few fixes:
    - Velocity value now will stay until next note arrives. Previously it dropped to 0 when note off arrived.
    - Removed clock and ST/SP from drum mode. Now this mode has eight trigger outs so clock and ST/SP will work as usual.
    - Changed clock, trigger and drum trigger length so they won't stay high on higher speeds.
    [MIDIClass.ino, firmware.ino]
2016-02-05 update to Bounce2 library (you'll need to add it to your Arduino library path)
2016-02-05 minor fix for previous change to bouncer code (prevented leaving cali mode by pressing the button)
    [firmware.ino]
2016-09-14 minor cleanup, fix readMIDIeeprom to not reset the eeprom if a poly mode is selected (ugh).
    [MIDIClass.h, MIDIClass.ino, MIDIHandle.ino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]

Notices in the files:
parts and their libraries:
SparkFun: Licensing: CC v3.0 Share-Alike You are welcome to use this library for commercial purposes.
